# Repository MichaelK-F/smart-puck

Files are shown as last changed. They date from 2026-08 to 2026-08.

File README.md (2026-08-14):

# Smart Puck
A Zigbee sensor puck

## Current Plan:
- microcontroller: ESP32-C6-MINI-1-N4 [https://jlcpcb.com/partdetail/EspressifSystems-ESP32_C6_MINI_1N4/C5736265](https://jlcpcb.com/partdetail/EspressifSystems-ESP32_C6_MINI_1N4/C5736265)
- USB-C port: USB-TYPE-C-018 [https://jlcpcb.com/partdetail/DEALON-USB_TYPE_C018/C2927038](https://jlcpcb.com/partdetail/DEALON-USB_TYPE_C018/C2927038)
- battery/power management:
  - battery connector: S2B-PH-K-S(LF)(SN) [https://jlcpcb.com/partdetail/JST-S2B_PH_K_S_LF_SN/C173752](https://jlcpcb.com/partdetail/JST-S2B_PH_K_S_LF_SN/C173752)
  - battery (2000mAh) [https://core-electronics.com.au/polymer-lithium-ion-battery-2000mah-38459.html](https://core-electronics.com.au/polymer-lithium-ion-battery-2000mah-38459.html)
  - BQ25185 (charger/power path) [https://jlcpcb.com/partdetail/TexasInstruments-BQ25185DLHR/C19725033](https://jlcpcb.com/partdetail/TexasInstruments-BQ25185DLHR/C19725033)
  - TPS63900 (buck/boost) [https://jlcpcb.com/partdetail/TexasInstruments-TPS63900DSKR/C1518762](https://jlcpcb.com/partdetail/TexasInstruments-TPS63900DSKR/C1518762)
  - MAX17048G (fuel gauge) [https://jlcpcb.com/partdetail/2777647-MAX17048GT10/C2682616](https://jlcpcb.com/partdetail/2777647-MAX17048GT10/C2682616)
- led: RS-C1415MBAR [https://jlcpcb.com/partdetail/3079315-RSC1415MBAR/C2874181](https://jlcpcb.com/partdetail/3079315-RSC1415MBAR/C2874181)
- boot mode button: GT-TZ084B-H015-L1 [https://jlcpcb.com/partdetail/GSwitch-GT_TZ084B_H015L1/C29780122](https://jlcpcb.com/partdetail/GSwitch-GT_TZ084B_H015L1/C29780122)
- temperature/humidity: SHT45-AD1F-R2 [https://jlcpcb.com/partdetail/Sensirion-SHT45_AD1FR2/C5360602](https://jlcpcb.com/partdetail/Sensirion-SHT45_AD1FR2/C5360602)
- mmwave: HLK-LD2420 [https://core-electronics.com.au/human-micro-motion-detection-mmwave-sensor.html](https://core-electronics.com.au/human-micro-motion-detection-mmwave-sensor.html)
- keyboard switches for buttons (cherry mx style)
- rotary encoder (ec11?)

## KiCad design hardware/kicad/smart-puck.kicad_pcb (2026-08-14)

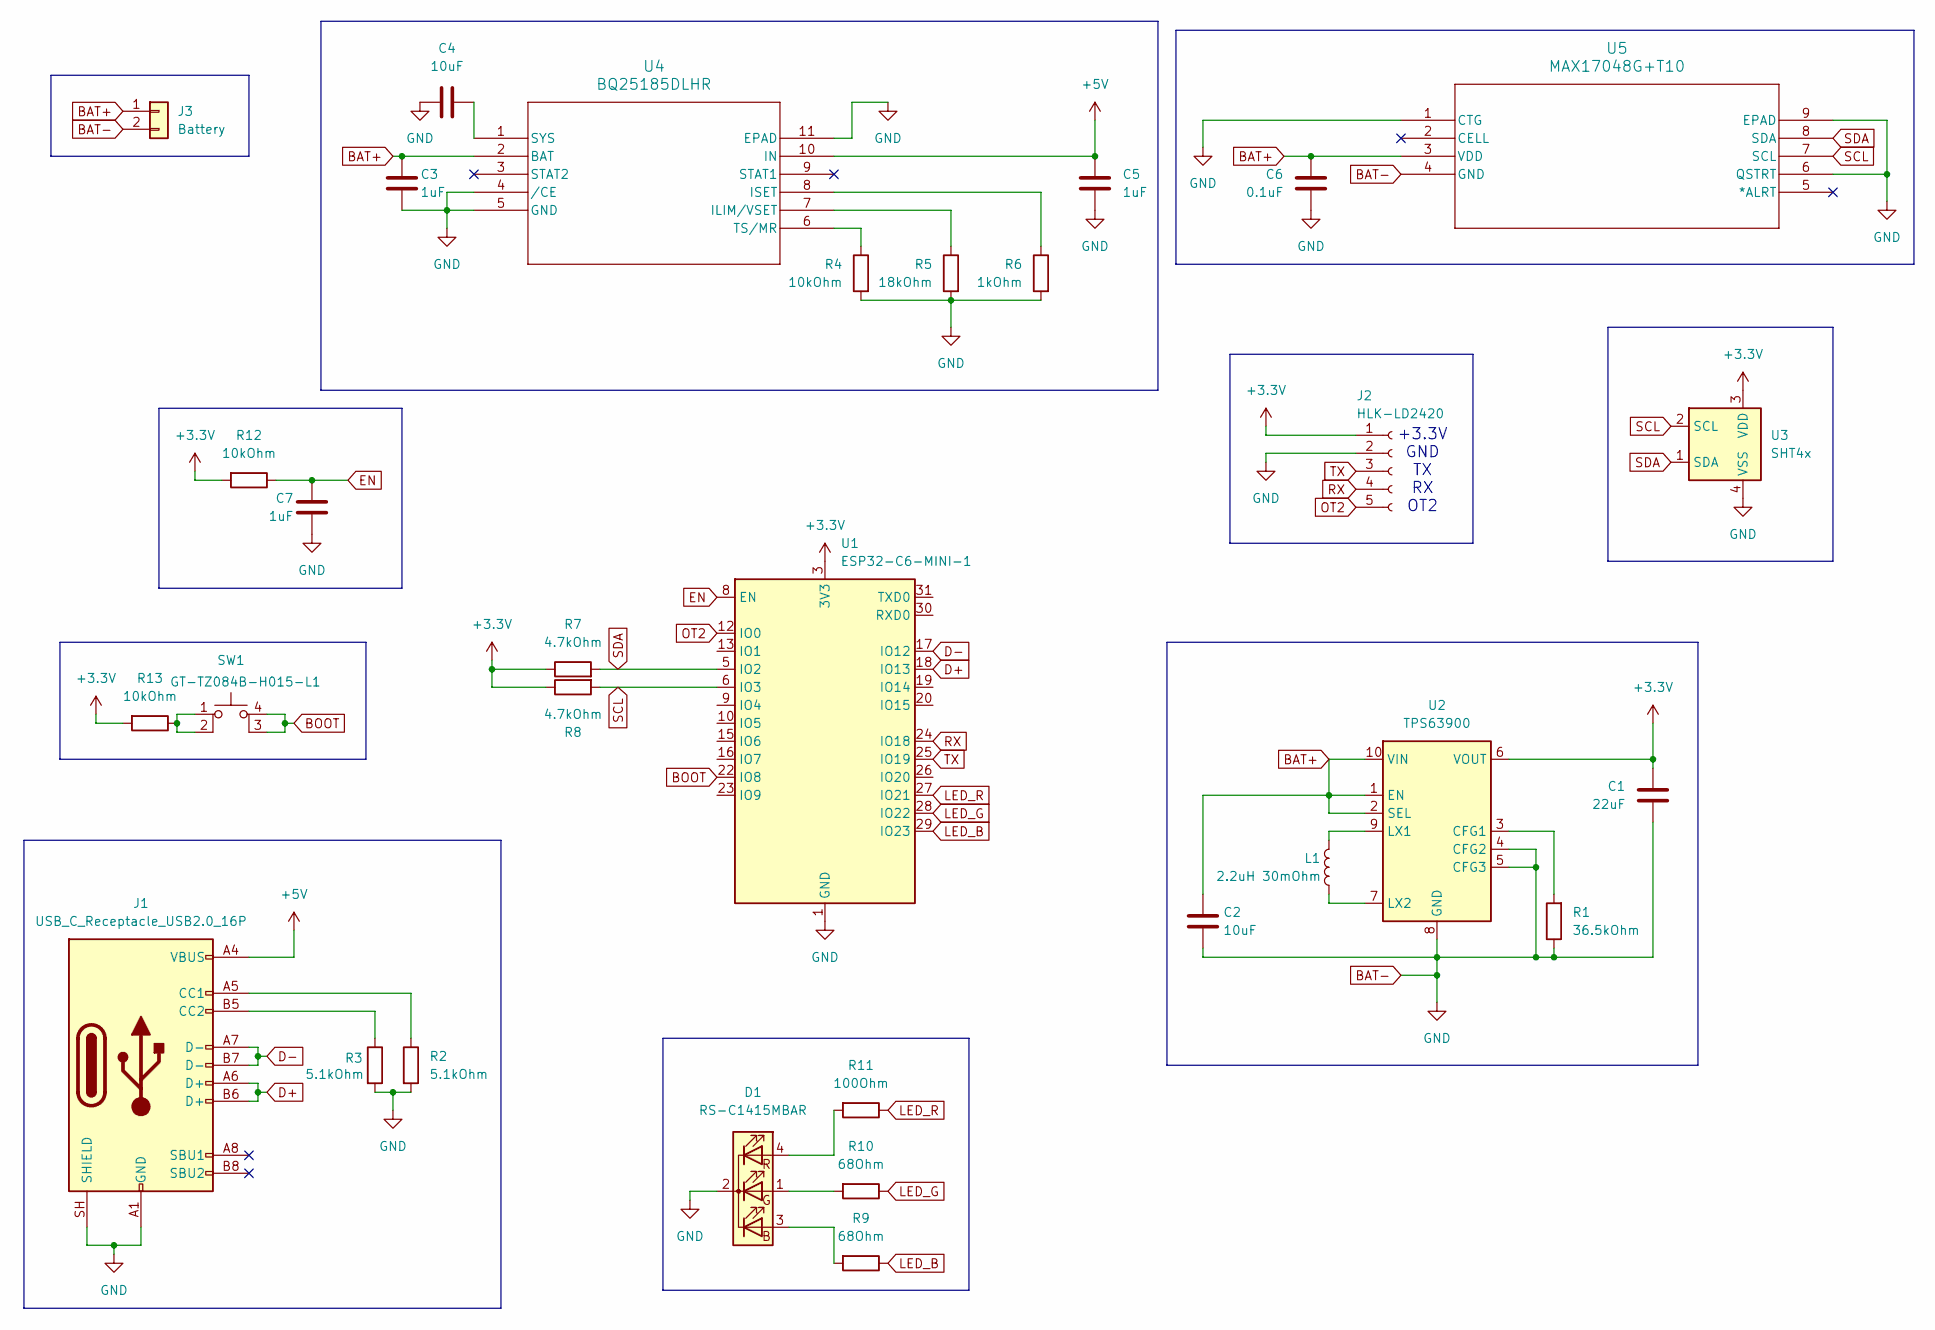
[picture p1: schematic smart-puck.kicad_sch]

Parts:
C1: 22uF; C_0603_1608Metric
C2, C4: 10uF; C_0603_1608Metric
C3, C5, C7: 1uF; C_0603_1608Metric
C6: 0.1uF; C_0603_1608Metric
D1: RS-C1415MBAR; LED-ARRAY-SMD_4P-L1.6-W1.6-BR-RD-CW
J1: USB_C_Receptacle_USB2.0_16P; USB_C_Receptacle_G-Switch_GT-USB-7010ASV
J2: HLK-LD2420; PinSocket_1x05_P2.54mm_Vertical
J3: Battery; JST_PH_S2B-PH-K_1x02_P2.00mm_Horizontal
L1: 2.2uH 30mOhm; L_TechFuse_SL0624
R1: 36.5kOhm; R_0402_1005Metric
R2, R3: 5.1kOhm; R_0402_1005Metric
R4, R12, R13: 10kOhm; R_0805_2012Metric
R5: 18kOhm; R_0603_1608Metric
R6: 1kOhm; R_0603_1608Metric
R7, R8: 4.7kOhm; R_0402_1005Metric
R9, R10: 68Ohm; R_0402_1005Metric
R11: 100Ohm; R_0402_1005Metric
SW1: GT-TZ084B-H015-L1; SW-SMD_4P-L5.2-W5.2-P3.70-LS6.4
U1: ESP32-C6-MINI-1
U2: TPS63900; WSON-10-1EP_2.5x2.5mm_P0.5mm_EP1.2x2mm_ThermalVias
U3: SHT4x; Sensirion_DFN-4_1.5x1.5mm_P0.8mm_SHT4x_NoCentralPad
U4: BQ25185DLHR; WSON10_DLH_TEX
U5: MAX17048G+T10; 21-0168E_T822-3_MXM

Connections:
+3.3V: C1.2, J2.1, R7.1, R8.1, R12.2, R13.2, U1.3 (3V3), U2.6 (VOUT), U3.3 (VDD)
+5V: C5.1, J1.A4 (VBUS), J1.A9 (VBUS), J1.B4 (VBUS), J1.B9 (VBUS), U4.10 (IN)
BAT+: C2.2, C3.1, C6.1, J3.1, U2.1 (EN), U2.2 (SEL), U2.10 (VIN), U4.2 (BAT), U5.3 (VDD)
BAT-: C1.1, C2.1, C3.2, C4.1, C5.2, C6.2, C7.2, D1.2 (K), J1.A1 (GND), J1.A12 (GND), J1.B1 (GND), J1.B12 (GND), J1.SH (SHIELD), J2.2, J3.2, R1.1, R2.2, R3.2, R4.2, R5.2, R6.2, U1.1 (GND), U1.2 (GND), U1.11 (GND), U1.14 (GND), U1.36 (GND), U1.37 (GND), U1.38 (GND), U1.39 (GND), U1.40 (GND), U1.41 (GND), U1.42 (GND), U1.43 (GND), U1.44 (GND), U1.45 (GND), U1.46 (GND), U1.47 (GND), U1.48 (GND), U1.49 (GND), U1.50 (GND), U1.51 (GND), U1.52 (GND), U1.53 (GND), U2.4 (CFG2), U2.5 (CFG3), U2.8 (GND), U2.11 (GND), U3.4 (VSS), U4.4 (/CE), U4.5 (GND), U4.11 (EPAD), U5.1 (CTG), U5.4 (GND), U5.6 (QSTRT), U5.9 (EPAD)
BOOT: SW1.3 (K), SW1.4 (A), U1.22 (IO8)
D+: J1.A6 (D+), J1.B6 (D+), U1.18 (IO13)
D-: J1.A7 (D-), J1.B7 (D-), U1.17 (IO12)
EN: C7.1, R12.1, U1.8 (EN)
LED_B: R9.1, U1.29 (IO23)
LED_G: R10.1, U1.28 (IO22)
LED_R: R11.1, U1.27 (IO21)
unnamed: D1.3 (BA), R9.2
unnamed: D1.1 (GA), R10.2
unnamed: D1.4 (RA), R11.2
unnamed: J1.A5 (CC1), R2.1
unnamed: J1.B5 (CC2), R3.1
unnamed: R13.1, SW1.1, SW1.2
unnamed: R1.2, U2.3 (CFG1)
unnamed: L1.2, U2.9 (LX1)
unnamed: L1.1, U2.7 (LX2)
unnamed: R5.1, U4.7 (ILIM/VSET)
unnamed: R6.1, U4.8 (ISET)
unnamed: C4.2, U4.1 (SYS)
unnamed: R4.1, U4.6 (TS/MR)
OT2: J2.5, U1.12 (IO0)
RX: J2.4, U1.24 (IO18)
SCL: R8.2, U1.6 (IO3), U3.2 (SCL), U5.7 (SCL)
SDA: R7.2, U1.5 (IO2), U3.1 (SDA), U5.8 (SDA)
TX: J2.3, U1.25 (IO19)

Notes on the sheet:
+3.3V GND TX RX OT2

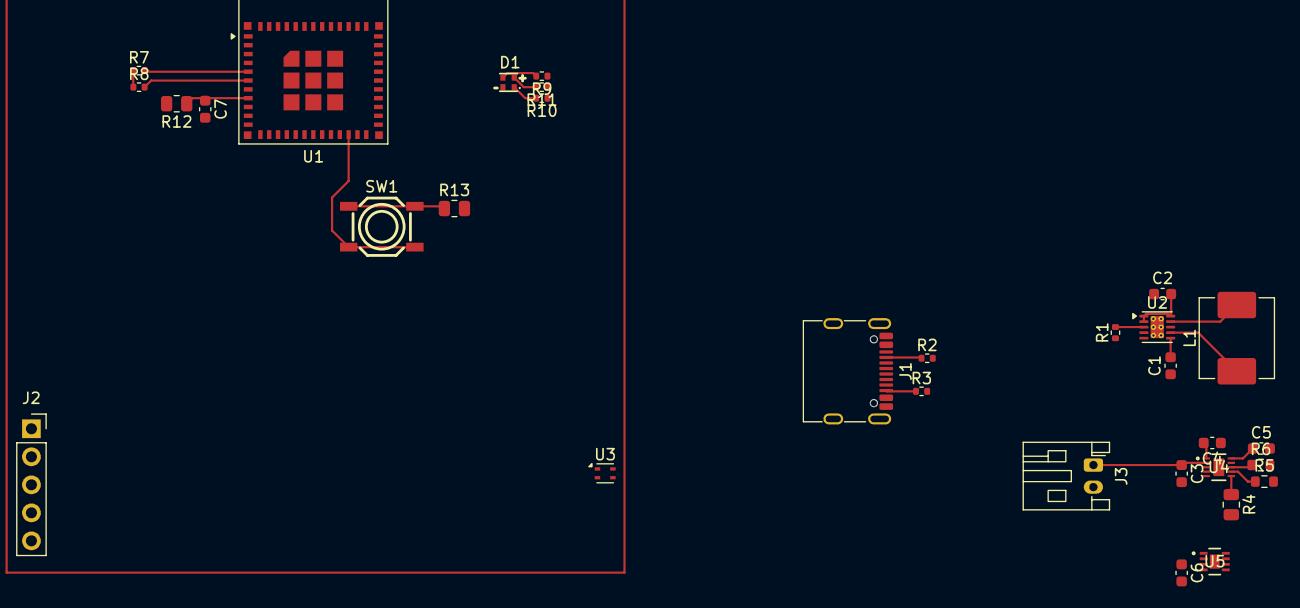
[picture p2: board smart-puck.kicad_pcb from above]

Board: 2 copper layers, 31 parts (0 on the bottom side), 29 nets.

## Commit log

2026-08-11 esp32-h2 is out of stock on jlcpcb :(
2026-08-11 set up kicad project
    [smart-puck.kicad_pcb, smart-puck.kicad_sch]
2026-08-11 added some ICs, will need to grab symbols and footprints for the rest of the ICs
    [smart-puck.kicad_pcb, smart-puck.kicad_sch]
2026-08-13 worked on schematic
    [smart-puck.kicad_pcb, smart-puck.kicad_sch]
2026-08-13 different led
2026-08-14 add button
2026-08-14 add battery connector
2026-08-14 add footprints and start working on pcb layout
    [smart-puck.kicad_pcb, smart-puck.kicad_sch]
